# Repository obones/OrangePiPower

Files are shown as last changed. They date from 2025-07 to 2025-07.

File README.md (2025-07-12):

PIC16F628A
  - Pin 5 (VSS) to ground
  - Pin 6 (RB0) towards mosfet Gate
  - Pin 7 (RB1) to ground to emulate false "powerloss" on bootup
  - Pin 11 (RB5) to ground to emilate "pi running" on bootup
  - Pin 14 (VDD) to +5V
  - Pin 18 (AN1) to potentiometer center point

FQP50N06  (G D S)
  - Gate to pin 6 (RB0) to drive the relay (emulated by a LED)
  - Source to ground
  - Drain to charge (LED -> resistor -> 5V)
  - 1k resitor between Gate and Source to avoid a floating gate

Potentiometer
  - Center to pin 18 (AN1) for duration
  - Top to +5
  - Bottom to GND

2N3904 in OpenCollector configuration towards PiRunning (E B C - flat fat towards you)
  - E to ground
  - B to controlled signal --> PA9
  - C to PiRunning (Pin 11 - RB5)
  - Pull down resistor between B and E (ground) 6.8k
Or 2N7000 in Open Drain configuration towards PiRunning (S G D - flat face towards you)
  - S to ground
  - G to controlled signal --> PA9
  - D to PiRunning (Pin 11 - RB5)
  - Pull down resistor between G and S (ground) 1k

BSS88 as a protection on PowerLoss on the OrangePi side
  - D to PowerLoss from OrangePiPower
  - G to 3.3V
  - S to OrangePi pin

From AN97055 via https://electronics.stackexchange.com/questions/82104/single-transistor-level-up-shifter

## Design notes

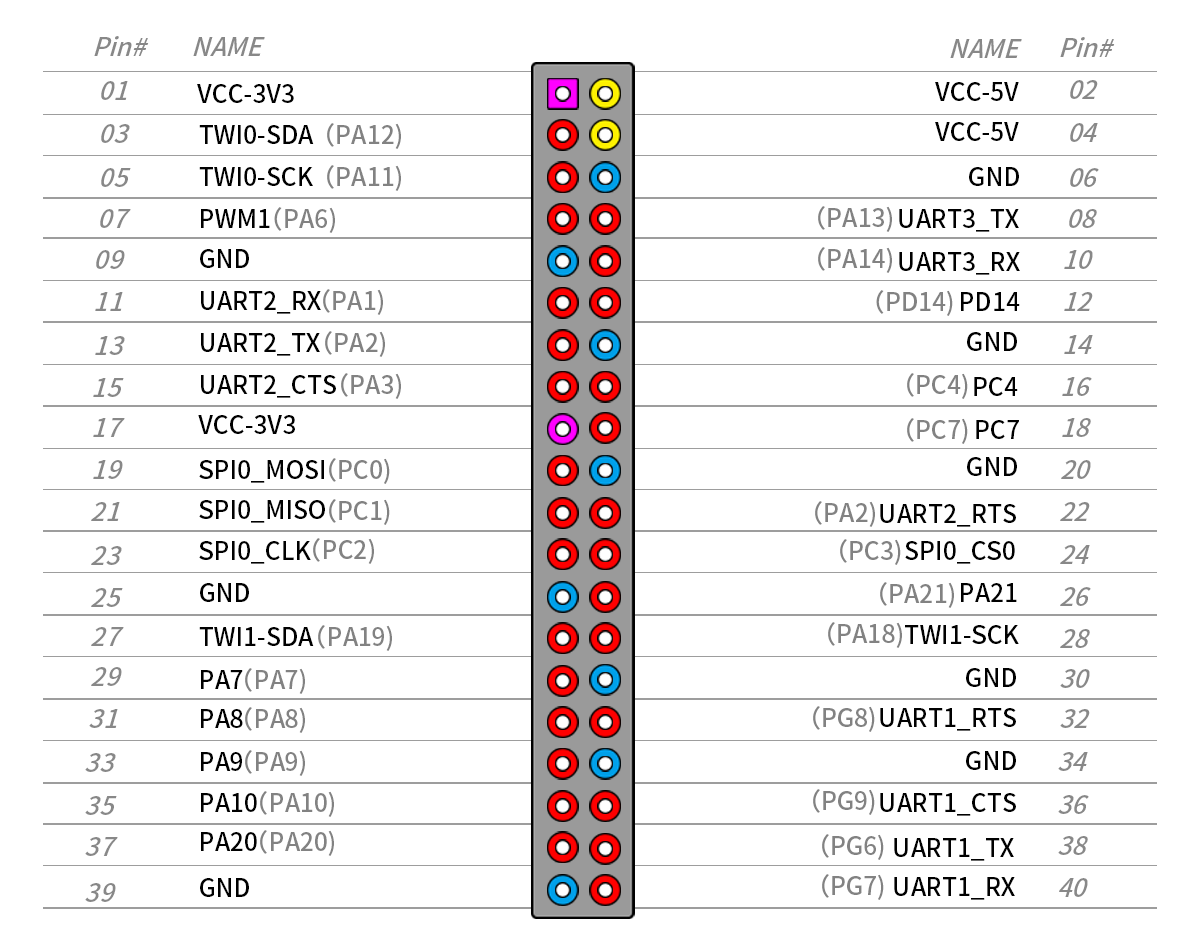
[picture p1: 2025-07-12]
PiPinout.png

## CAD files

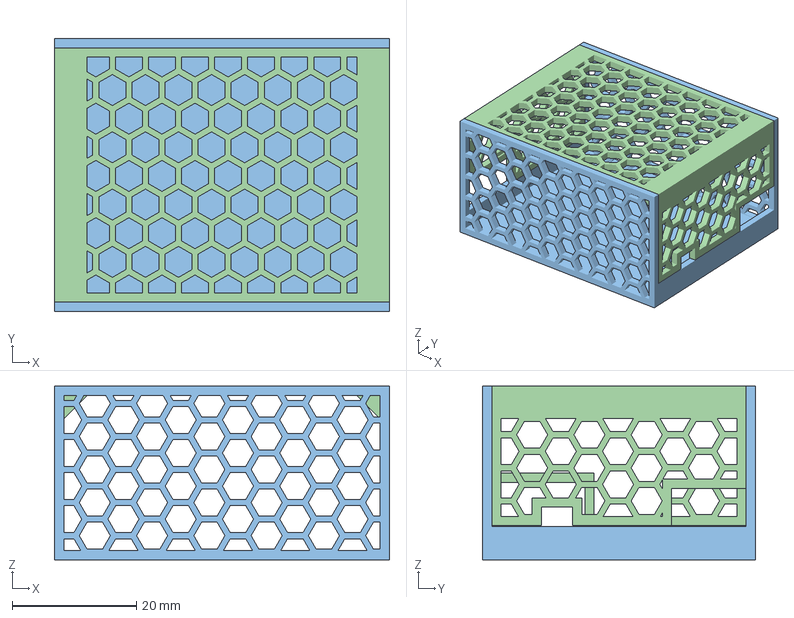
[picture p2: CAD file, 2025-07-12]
Boitier OrangePi Control.FCStd
54.0 x 44.0 x 28.0 mm
Base
Cover
Base (Meshed)
Cover (Meshed)

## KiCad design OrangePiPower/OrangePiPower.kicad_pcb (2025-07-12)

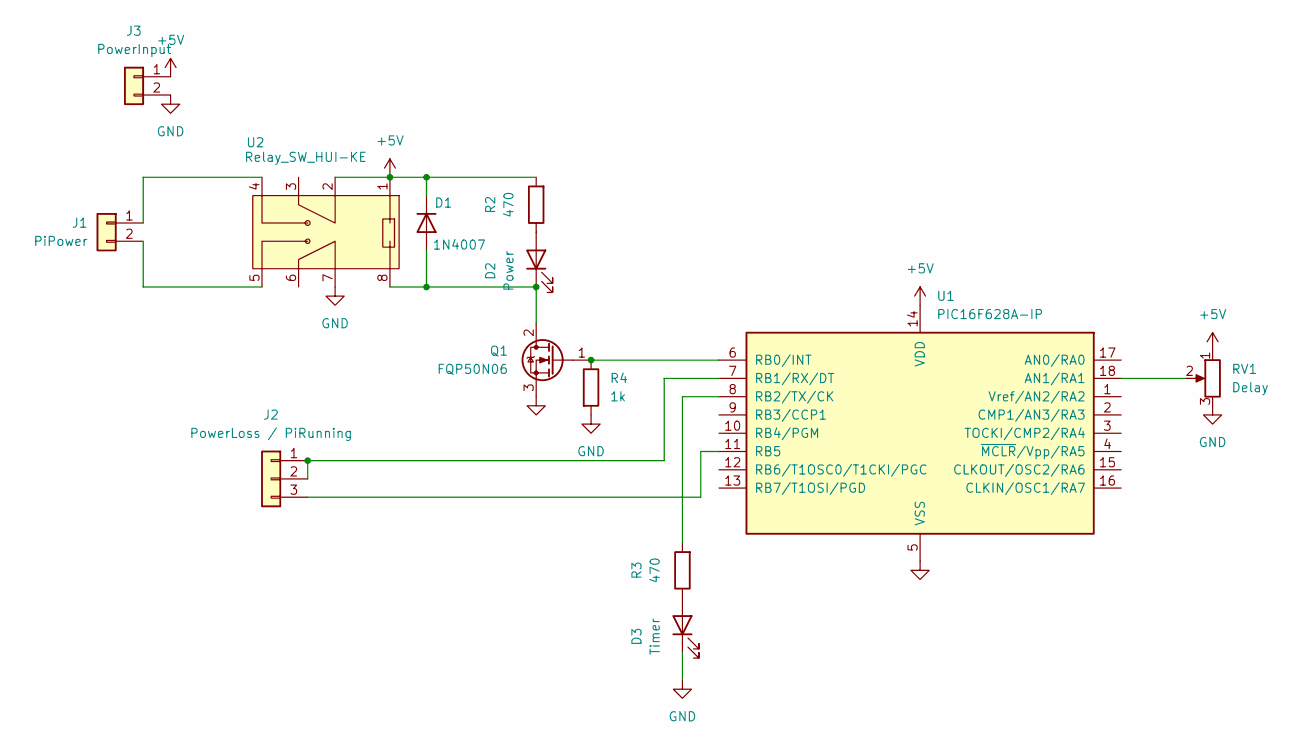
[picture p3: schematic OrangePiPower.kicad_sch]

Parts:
D1: 1N4007; D_DO-41_SOD81_P10.16mm_Horizontal
D2: Power; LED_D3.0mm_Clear
D3: Timer; LED_D3.0mm_Clear
J1: PiPower; PinHeader_1x02_P2.54mm_Vertical
J2: PowerLoss / PiRunning; PinHeader_1x03_P2.54mm_Vertical
J3: PowerInput; PinHeader_1x02_P2.54mm_Vertical
Q1: FQP50N06; TO-220-3_Vertical
R2, R3: 470; R_Axial_DIN0204_L3.6mm_D1.6mm_P5.08mm_Horizontal
R4: 1k; R_Axial_DIN0204_L3.6mm_D1.6mm_P5.08mm_Horizontal
RV1: Delay; POT_3386G
U1: PIC16F628A-IP; DIP-18_W7.62mm_LongPads
U2: Relay_SW_HUI-KE; Relay_HUI-KE

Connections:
+5V: D1.1 (K), J3.1, R2.2, RV1.1, U1.14 (VDD), U2.1, U2.2
GND: D3.1 (K), J3.2, Q1.3 (S), R4.2, RV1.3, U1.5 (VSS), U2.7
unnamed: D1.2 (A), D2.1 (K), Q1.2 (D), U2.8
unnamed: D2.2 (A), R2.1
unnamed: D3.2 (A), R3.1
unnamed: J1.1, U2.4
unnamed: J1.2, U2.5
unnamed: J2.1, J2.2, U1.7 (RB1/RX/DT)
unnamed: J2.3, U1.11 (RB5)
unnamed: Q1.1 (G), R4.1, U1.6 (RB0/INT)
unnamed: RV1.2, U1.18 (AN1/RA1)
unnamed: R3.2, U1.8 (RB2/TX/CK)

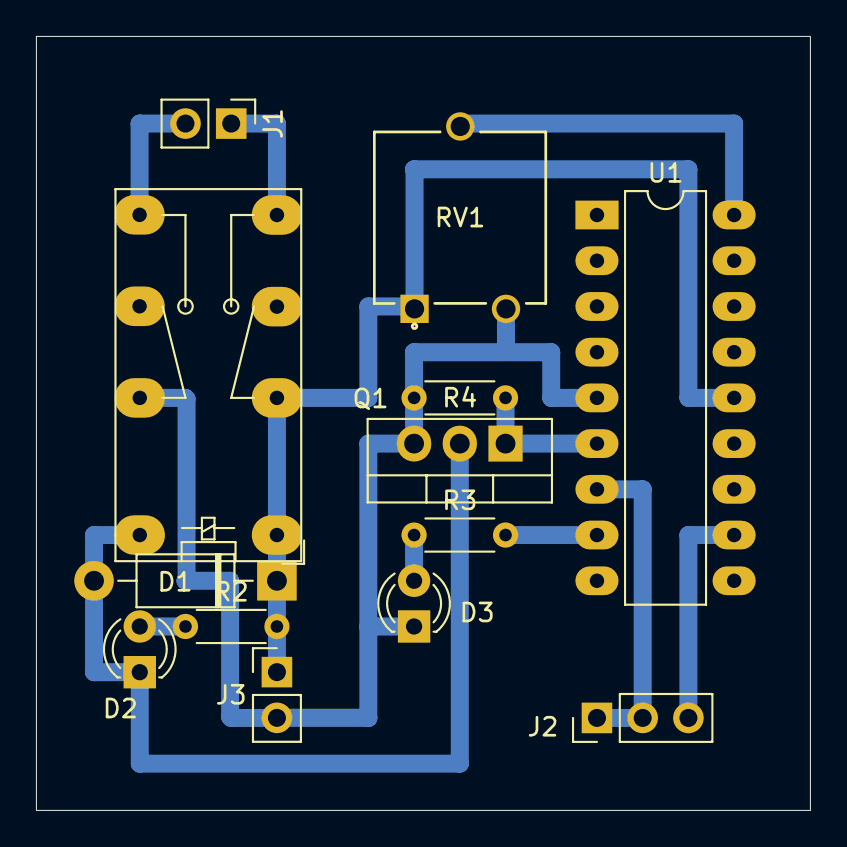
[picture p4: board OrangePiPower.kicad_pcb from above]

Board: 2 copper layers, 43.0 x 43.0 mm, 13 parts (0 on the bottom side), 12 nets.

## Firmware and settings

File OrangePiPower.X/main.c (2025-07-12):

// PIC16F628A Configuration Bit Settings
// 'C' source line config statements
// CONFIG
#pragma config FOSC = INTOSCIO  // Oscillator Selection bits (INTOSC oscillator: I/O function on RA6/OSC2/CLKOUT pin, I/O function on RA7/OSC1/CLKIN)
#pragma config WDTE = OFF       // Watchdog Timer Enable bit (WDT disabled)
#pragma config PWRTE = ON       // Power-up Timer Enable bit (PWRT enabled)
#pragma config MCLRE = OFF      // RA5/MCLR/VPP Pin Function Select bit (RA5/MCLR/VPP pin function is digital input, MCLR internally tied to VDD)
#pragma config BOREN = ON       // Brown-out Detect Enable bit (BOD enabled)
#pragma config LVP = OFF        // Low-Voltage Programming Enable bit (RB4/PGM pin has digital I/O function, HV on MCLR must be used for programming)
#pragma config CPD = OFF        // Data EE Memory Code Protection bit (Data memory code protection off)
#pragma config CP = OFF         // Flash Program Memory Code Protection bit (Code protection off)

// #pragma config statements should precede project file includes.
// Use project enums instead of #define for ON and OFF.

#include <xc.h>

/*
 * File:   main.c
 * Author: Olivier
 *
 * Created on 20 décembre 2024, 22:53
 */

// Pins usage
//    1 - Input  - VREF - looped to comparator             -> Do not connect anything here
//   18 - Input  - AN1  - to comparator                    -> Duration, Variable resistor
//    6 - Output - RB0                                     -> PiPower
//    7 - Input  - RB1  - WeakPullUp                       -> PowerLoss
//    8 - Output - RB2  -                                  -> TMR0 overflow (toggled)
//   11 - Input  - RB5  - WeakPullUp - Interrupt on change -> PiRunning (inverted signal from pin)

// we use the internal oscillator in "slow" mode
#define _XTAL_FREQ 48000

#include <xc.h>
#include <pic16f628a.h>
#include <stdint.h>

#define PiPower PORTBbits.RB0
#define PowerLoss PORTBbits.RB1
#define PiRunning (!PORTBbits.RB5)
#define Tmr0Overflow PORTBbits.RB2

// Direct value as it controls a N channel mosfet
#define PowerOn 1
#define PowerOff 0 

// use a define to "inline" the function and avoid the 1510 advisory about using it both in main and the ISR
#define disableTimer0Interrupt() INTCONbits.T0IE = 0
#define enableTimer0Interrupt()  INTCONbits.T0IE = 1

uint8_t readExpectedDelay();

uint8_t currentDelay = 0;

void main(void) {
    // setup ports as early as possible
    TRISAbits.TRISA1 = 1;  // input 
    TRISAbits.TRISA2 = 1;  // input for VREF to be seen

    TRISBbits.TRISB0 = 0;  // output
    TRISBbits.TRISB1 = 1;  // input
    TRISBbits.TRISB2 = 0;  // output
    TRISBbits.TRISB5 = 1;  // input
    
    PORTB = 0x00; // everything low level by default
    
    // activate power to the PI
    PiPower = PowerOn;
    
    PCONbits.OSCF = 0; // 48kHz to get long delays from TMR0
    
    OPTION_REGbits.nRBPU = 0;  // weak pull ups on port B
    OPTION_REGbits.T0CS = 0;  // TMR0 on internal clock
    OPTION_REGbits.PSA = 0;  // Prescaler for TMR0
    OPTION_REGbits.PS = 0b101; // 1:64 prescaler 
    
    // Timer0 will overflow every (4 * 64 * 256) / 48000 = 1.37 seconds which gives us
    // a wait time with 16 levels from 1.37 to 16*1.37 = 21.84 seconds
    
    INTCONbits.GIE = 1; // enable interrupts
    disableTimer0Interrupt(); // Timer0 interrupt (disable by default)
    INTCONbits.RBIE = 0; // Interrupts on port B (disable by default)
    
    CMCONbits.CM = 0b101; // one comparator (C2) on RA1/RA2(VREF)
    CMCONbits.C2INV = 0;  // comparator C2 output is not inverted
    
    VRCONbits.VREN = 1; // VREF enabled
    VRCONbits.VROE = 1; // VREF output on RA2
    VRCONbits.VRR = 0; // High range
    
    Tmr0Overflow = 0;
    TMR0 = 0;

    // let everything settle
    __delay_ms(100);
    
    // enable portb interrupts now that setup is done
    INTCONbits.RBIE = 1;
    
    while (1)
    {
        
        int expectedDelay = readExpectedDelay();
        
        if (PowerLoss)
        {
            if (currentDelay > expectedDelay)
            {
                disableTimer0Interrupt();
                Tmr0Overflow = 0;
                currentDelay = 0;
                PiPower = PowerOff;
            }
        }
        else
        {
            disableTimer0Interrupt();
            Tmr0Overflow = 0;
            PiPower = PowerOn;
        }
    }
}

void StartTimer()
{
    TMR0 = 0;
    Tmr0Overflow = 0;
    currentDelay = 0;
    enableTimer0Interrupt();
}

void __interrupt() interruptServiceRoutine(void)
{
    if (INTCONbits.RBIF)
    {
        INTCONbits.RBIF = 0;  // must reset for next time
        
        if (INTCONbits.RBIE)  // the port B change flag may be set even if the interrupt is disabled
        {
            if (PowerLoss && !PiRunning)
            {
                StartTimer();
            }
        }
    }
    
    if (INTCONbits.T0IF)
    {
        INTCONbits.T0IF = 0;  // must reset for next time
        
        if (INTCONbits.T0IE)  // the timer overflow flag keeps getting set even if the interrupt is disabled
        {
            Tmr0Overflow = 1u - Tmr0Overflow;
            currentDelay++;
        }
    }
}

uint8_t readExpectedDelay()
{
    // As there is no ADC on the 16F628A, we use the comparator module to 
    // compare VREF to the analog voltage on RA1
    // Changing VREF repeatedly until the comparison tells us RA1 is above VREF
    // gives us 16 discrete levels from the analog voltage, aka "poor man's ADC".
    uint8_t result = 0;
    do 
    {
        VRCONbits.VR = result;
        __delay_us(10 + 5);  // 10 for VREF settling + 5 for comparator update
        result++;
    }
    while ((result <= 0x0F) && (!CMCONbits.C2OUT));
    
    return result;
}

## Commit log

2025-07-12 feat: initial content
    [OrangePiPower.kicad_pcb, OrangePiPower.kicad_sch]
2025-07-12 feat: 3D model for the final PCB
    [Boitier OrangePi Control.FCStd]
